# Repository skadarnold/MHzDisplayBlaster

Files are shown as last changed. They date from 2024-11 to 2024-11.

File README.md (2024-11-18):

# ST-6A Blaster

This is a fork of the MHzDisplayBlaster by Scrap Computing
https://github.com/scrapcomputing/MHzDisplayBlaster

It has been reworked to clone a ST-6A style display board, particularly designed for a Baby AT style case. This case badged as a Gecco was likely the name of the company that built the computer and not the case. This display board is not a perfect match to a ST-6A display, but was the closest I could identify to the style. It will likely need to be modified for your particular case use.

# Assembly Tips
This video shows assembly of the original MHzDisplayBlaster, which is a similar build process.
- Video showing the assembly of rev.0.1 PCB: https://www.youtube.com/watch?v=a4iVehn7APU
 
# Display Configuration
- Each segment of the 7-segment display is configured individually with a jumper
- Each segment corresponds to a pin in the configuration headers
- You can short that pin with one of the neighboring state pins (forming a `T` shape) to set its state, which can be one of the following:
  1. ON when Turbo switch is OFF (jumper to position 1)
  2. ON when Turbo switch is ON (jumper to position 2)
  3. Always ON (jumper to position 3)
  4. Always OFF (no jumper)



# Bill of materials

Gerber files are published in the releases: https://github.com/skadarnold/MHzDisplayBlaster/releases

Reference      | Quantity| Value    | Footprint/Comments
---------------|---------|----------|----------
U1             | 1       |(e.g., LTD-6440G) | 18-DIP (0.600", 15.24mm distance between top and bottom row pins) 2-Digit 7-Segment Display Common Cathode 0.56" Red
J1 J2          | 2       |Conn_02x15| Connector Male PinHeader 2x15 P2.54mm Vertical
J4             | 1       |Conn_01x06| Connector Male PinHeader 1x06 P2.54mm Vertical
R1             | 1       | >= 39 Ohm (100 Ohms recommended)| 3.6 x 1.6mm 1/4 Watt resistor.
R2 R3          | 2       | 330 - 1k Ohm | 3.6 x 1.6mm 1/4 Watt resistor.
U2             | 1       | 74LS04 (	SN7404DR ) | SOIC-14
Jumpers        | 5      |          | 2.54mm pitch jumpers

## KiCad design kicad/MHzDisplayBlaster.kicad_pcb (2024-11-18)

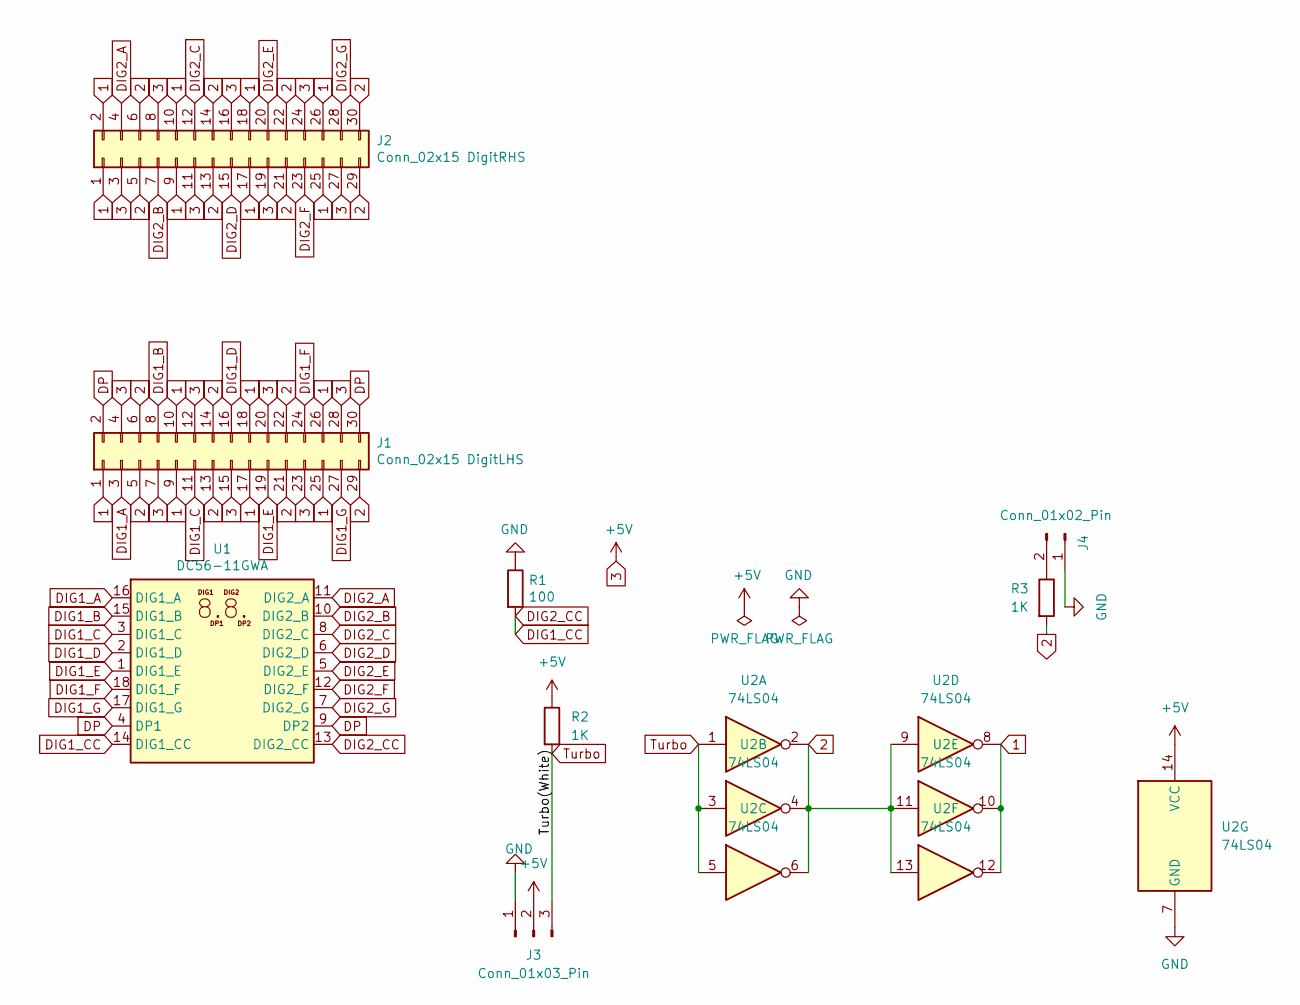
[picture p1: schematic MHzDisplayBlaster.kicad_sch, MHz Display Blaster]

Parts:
J1: Conn_02x15 DigitLHS; PinHeader_2x15_P2.54mm_Vertical
J2: Conn_02x15 DigitRHS; PinHeader_2x15_P2.54mm_Vertical
J3: Conn_01x03_Pin; PinHeader_1x03_P2.54mm_Vertical
J4: Conn_01x02_Pin; PinHeader_1x02_P2.54mm_Vertical
R1: 100; R_Axial_DIN0204_L3.6mm_D1.6mm_P5.08mm_Horizontal
R2, R3: 1K; R_Axial_DIN0204_L3.6mm_D1.6mm_P5.08mm_Horizontal
U1: DC56-11GWA; DA56-11CGKWA
U2: 74LS04; SOIC-14_3.9x8.7mm_P1.27mm

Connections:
1: J1.1, J1.9, J1.10, J1.17, J1.18, J1.25, J1.26, J2.1, J2.2, J2.9, J2.10, J2.17, J2.18, J2.25, J2.26, U2.8, U2.10, U2.12
2: J1.5, J1.6, J1.13, J1.14, J1.21, J1.22, J1.29, J2.5, J2.6, J2.13, J2.14, J2.21, J2.22, J2.29, J2.30, R3.2, U2.2, U2.4, U2.6, U2.9, U2.11, U2.13
3: J1.4, J1.7, J1.12, J1.15, J1.20, J1.23, J1.28, J2.3, J2.8, J2.11, J2.16, J2.19, J2.24, J2.27, J3.2, R2.1, U2.14 (VCC)
DIG1_A: J1.3, U1.16 (DIG1_A)
DIG1_B: J1.8, U1.15 (DIG1_B)
DIG1_C: J1.11, U1.3 (DIG1_C)
DIG1_CC: R1.2, U1.13 (DIG2_CC), U1.14 (DIG1_CC)
DIG1_D: J1.16, U1.2 (DIG1_D)
DIG1_E: J1.19, U1.1 (DIG1_E)
DIG1_F: J1.24, U1.18 (DIG1_F)
DIG1_G: J1.27, U1.17 (DIG1_G)
DIG2_A: J2.4, U1.11 (DIG2_A)
DIG2_B: J2.7, U1.10 (DIG2_B)
DIG2_C: J2.12, U1.8 (DIG2_C)
DIG2_D: J2.15, U1.6 (DIG2_D)
DIG2_E: J2.20, U1.5 (DIG2_E)
DIG2_F: J2.23, U1.12 (DIG2_F)
DIG2_G: J2.28, U1.7 (DIG2_G)
DP: J1.2, J1.30, U1.4 (DP1), U1.9 (DP2)
GND: J3.1, J4.1, R1.1, U2.7 (GND)
unnamed: J4.2, R3.1
Turbo: J3.3, R2.2, U2.1, U2.3, U2.5

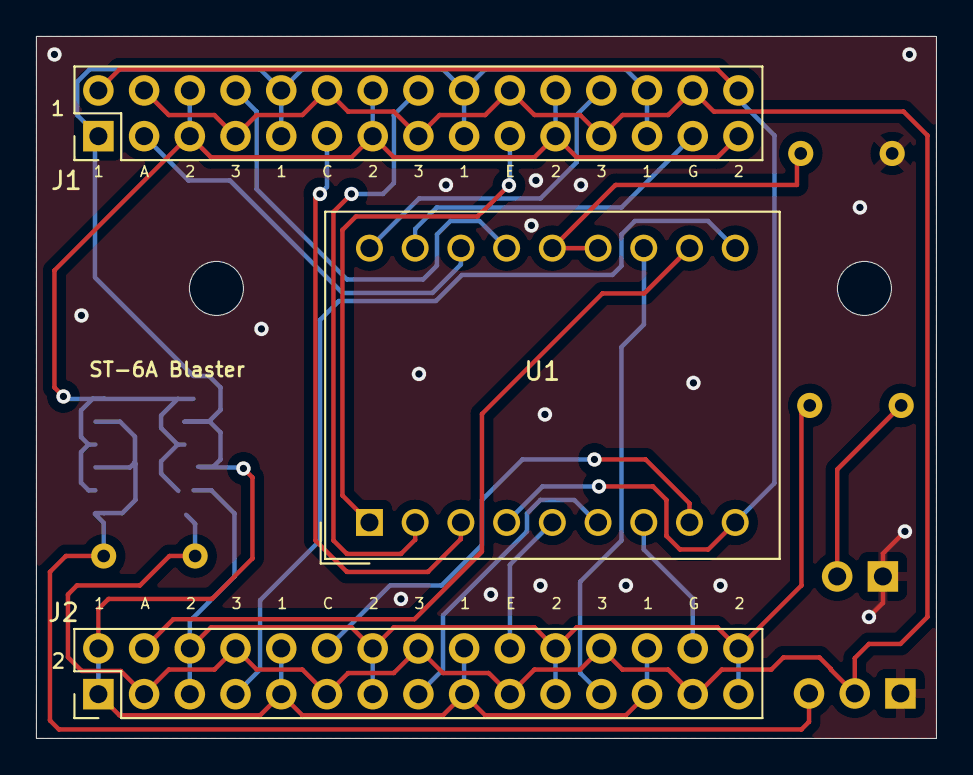
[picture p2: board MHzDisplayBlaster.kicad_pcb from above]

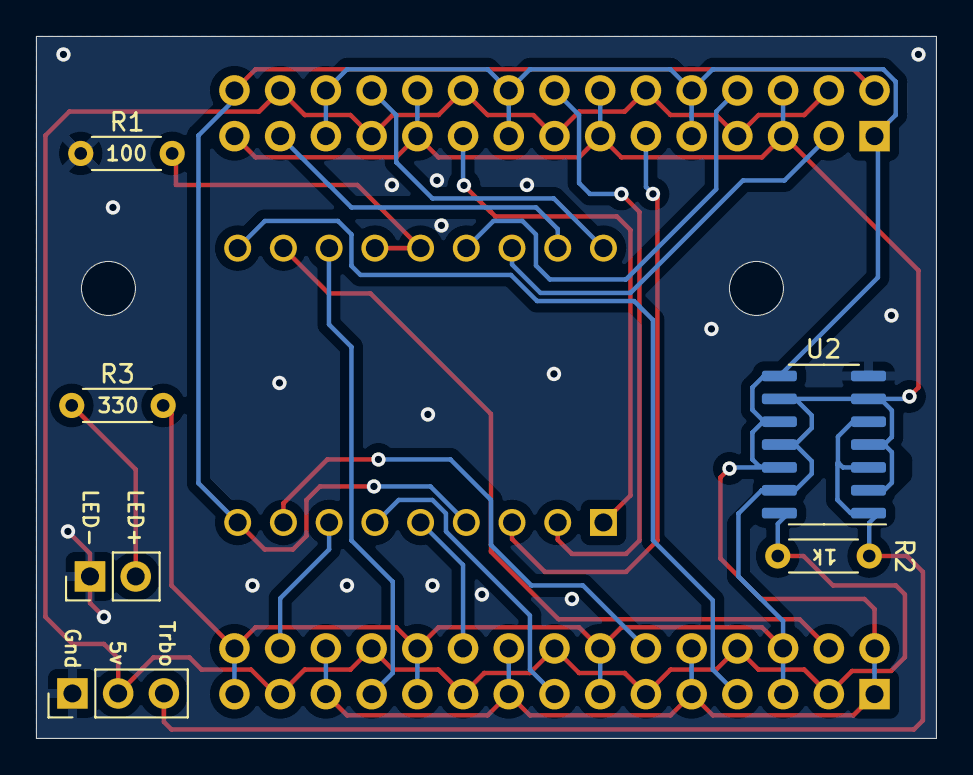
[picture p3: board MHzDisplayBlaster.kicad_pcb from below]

Board: 2 copper layers, 50.0 x 39.0 mm, 9 parts (6 on the bottom side), 22 nets.

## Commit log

2024-11-18 Initial Redesign
    Layout rearranged for Gecco labeled Baby AT case. Not even ready as a beta release.
    [MHzDisplayBlaster.kicad_pcb, MHzDisplayBlaster.kicad_sch]
2024-11-18 Split 7-pin connector
    [MHzDisplayBlaster.kicad_pcb, MHzDisplayBlaster.kicad_sch]
2024-11-18 PCB Arrange
    [MHzDisplayBlaster.kicad_pcb]
2024-11-18 Update Schematic 74LS04
    [MHzDisplayBlaster.kicad_pcb, MHzDisplayBlaster.kicad_sch]
2024-11-18 Cleanup and Routing
    [MHzDisplayBlaster.kicad_pcb, MHzDisplayBlaster.kicad_sch]
2024-11-18 Small cleanup to text
    [MHzDisplayBlaster.kicad_pcb]
2024-11-18 Remove ground plane
    [MHzDisplayBlaster.kicad_pcb]
2024-11-18 Major Refactor and Cleanup
    [MHzDisplayBlaster.dsn, MHzDisplayBlaster.kicad_pcb, MHzDisplayBlaster.kicad_sch]
2024-11-18 Remove Rule Zones and extend trace for screw clearance
    [MHzDisplayBlaster.kicad_pcb]
2024-11-18 Move R2 to Back
    [MHzDisplayBlaster.kicad_pcb]
2024-11-18 Move J3 Silk to Back
    [MHzDisplayBlaster.kicad_pcb]
2024-11-18 Add vias to fill in ground planes
    [MHzDisplayBlaster.kicad_pcb]
2024-11-18 Raise J3 to higher position
    [MHzDisplayBlaster.kicad_pcb]
2024-11-18 Adjust via position for J1 text
    [MHzDisplayBlaster.kicad_pcb]
2024-11-18 Fix missing routes on 7404
    [MHzDisplayBlaster.kicad_pcb]
2024-11-18 More trace cleanup
    [MHzDisplayBlaster.kicad_pcb]
2024-11-18 Add Graphical Notes
    [MHzDisplayBlaster.kicad_pcb]
2024-11-18 Connect Display pin 4 & Trace Cleanup
    [MHzDisplayBlaster.kicad_pcb]
2024-11-18 Refill ground planes
    [MHzDisplayBlaster.kicad_pcb]
2024-11-18 Add Turbo LED Header
    [MHzDisplayBlaster.kicad_pcb, MHzDisplayBlaster.kicad_sch]
2024-11-18 Adjust ground plane vias
    [MHzDisplayBlaster.kicad_pcb]
2024-11-18 Slight adjustment to display and mounting holes
    [MHzDisplayBlaster.kicad_pcb]
2024-11-18 Change HEX Inverter position, clean up layout
    [MHzDisplayBlaster.kicad_pcb, MHzDisplayBlaster.kicad_sch]
2024-11-18 Rotate HEX inverter, finalize
    [MHzDisplayBlaster.kicad_pcb]
